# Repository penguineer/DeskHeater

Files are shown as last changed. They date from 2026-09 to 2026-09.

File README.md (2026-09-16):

# Desk Heater

> Low-power heated desktop for reducing conductive heat loss while working in a cool room.

This project adds a thin 24 V carbon heating film underneath a bamboo desktop. The goal is not to make the desk feel hot, but to keep the work surface close enough to room/body-neutral temperature that it no longer cools hands and forearms during long work sessions in winter.

The controller is based on an ESP8266 (ESP-12E) and provides:

- temperature monitoring with multiple NTC sensors
- hardware over-temperature protection independent of the ESP
- current, voltage, power and energy measurement
- slow duty-cycle control of the approximately 60 W heating film
- UART and Wi-Fi connectivity for monitoring and future controls

The KiCad design for the controller is in [`Controller/`](Controller/).

## Status

Work in progress. The electrical and mechanical design is currently being prototyped and characterized.

## License



This work is licensed under a [Creative Commons Attribution-ShareAlike 4.0 International License](http://creativecommons.org/licenses/by-sa/4.0/).

BY: Stefan Haun (mail@tuxathome.de)

See [LICENSE.txt](LICENSE.txt) for details.

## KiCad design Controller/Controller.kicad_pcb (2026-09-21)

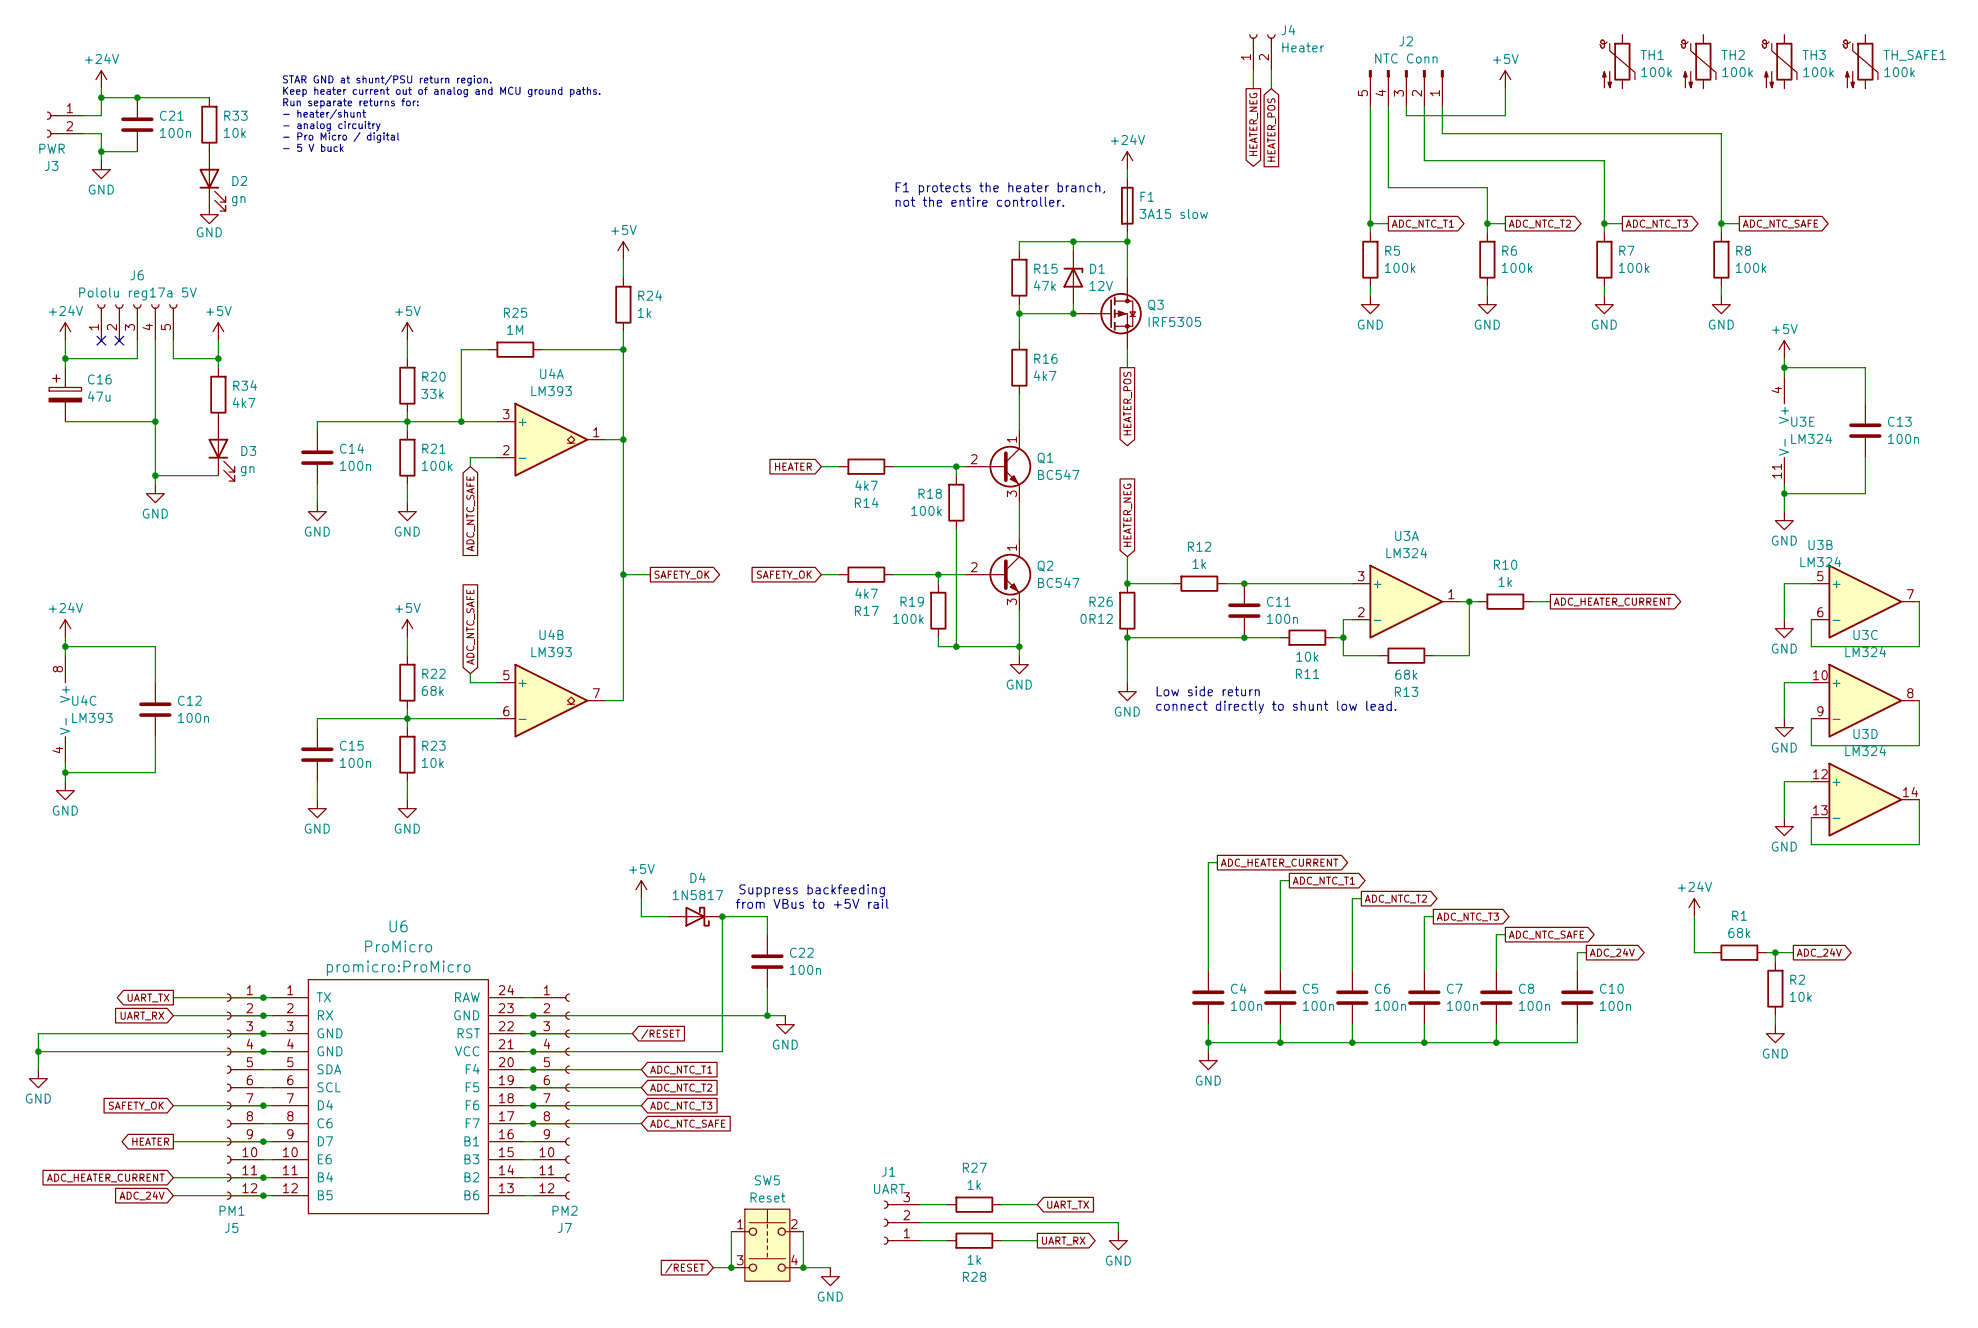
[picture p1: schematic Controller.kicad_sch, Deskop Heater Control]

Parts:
C4, C5, C6, C7, C8, C10, C11, C12, C13, C14, C15, C21, C22: 100n; C_Disc_D4.3mm_W1.9mm_P5.00mm
C16: 47u; CP_Radial_D6.3mm_P2.50mm
D1: 12V; D_DO-41_SOD81_P7.62mm_Horizontal
D2, D3: gn; LED_D3.0mm
D4: 1N5817; D_DO-41_SOD81_P10.16mm_Horizontal
F1: 3A15 slow; Fuseholder_Cylinder-5x20mm_Stelvio-Kontek_PTF78_Horizontal_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
J1: UART; PinHeader_1x03_P2.54mm_Vertical
J2: NTC Conn; JST_EH_B5B-EH-A_1x05_P2.50mm_Vertical
J3: PWR; JST_NV_B02P-NV_1x02_P5.00mm_Vertical
J4: Heater; JST_NV_B02P-NV_1x02_P5.00mm_Vertical
J5: PM1; PinSocket_1x12_P2.54mm_Vertical
J6: Pololu reg17a 5V; PinHeader_1x05_P2.54mm_Vertical
J7: PM2; PinSocket_1x12_P2.54mm_Vertical
Q1, Q2: BC547; TO-92_Inline
Q3: IRF5305; TO-220-3_Vertical
R1, R13, R22: 68k; R_Axial_DIN0207_L6.3mm_D2.5mm_P7.62mm_Horizontal
R2, R11, R23, R33: 10k; R_Axial_DIN0207_L6.3mm_D2.5mm_P7.62mm_Horizontal
R5, R6, R7, R8, R18, R19, R21: 100k; R_Axial_DIN0207_L6.3mm_D2.5mm_P7.62mm_Horizontal
R10, R12, R24, R27, R28: 1k; R_Axial_DIN0207_L6.3mm_D2.5mm_P7.62mm_Horizontal
R14, R16, R17, R34: 4k7; R_Axial_DIN0207_L6.3mm_D2.5mm_P7.62mm_Horizontal
R15: 47k; R_Axial_DIN0207_L6.3mm_D2.5mm_P7.62mm_Horizontal
R20: 33k; R_Axial_DIN0207_L6.3mm_D2.5mm_P7.62mm_Horizontal
R25: 1M; R_Axial_DIN0207_L6.3mm_D2.5mm_P7.62mm_Horizontal
R26: 0R12; R_Axial_DIN0614_L14.3mm_D5.7mm_P15.24mm_Horizontal
SW5: Reset; SW_DIP_SPSTx02_Slide_6.7x6.64mm_W7.62mm_P2.54mm_LowProfile
TH1, TH2, TH3: 100k; LQFP-100_14x14mm_P0.5mm
TH_SAFE1: 100k; LQFP-100_14x14mm_P0.5mm
U3: LM324; DIP-14_W7.62mm_LongPads
U4: LM393; DIP-8_W7.62mm_LongPads
U6: ProMicro

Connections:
+5V: C13.1, D4.2 (A), J2.3, J6.5, R20.2, R22.2, R24.2, R34.2, U3.4 (V+)
+24V: C12.1, C16.1, C21.1, F1.1, J3.1, J6.3, R1.1, R33.2, U4.8 (V+)
ADC_24V: C10.1, J5.12, R1.2, R2.2, U6.12 (B5)
ADC_HEATER_CURRENT: C4.1, J5.11, R10.1, U6.11 (B4)
ADC_NTC_SAFE: C8.1, J2.1, J7.8, R8.2, U4.2 (-), U4.5 (+), U6.17 (F7)
ADC_NTC_T1: C5.1, J2.5, J7.5, R5.2, U6.20 (F4)
ADC_NTC_T2: C6.1, J2.4, J7.6, R6.2, U6.19 (F5)
ADC_NTC_T3: C7.1, J2.2, J7.7, R7.2, U6.18 (F6)
GND: C4.2, C5.2, C6.2, C7.2, C8.2, C10.2, C11.2, C12.2, C13.2, C14.2, C15.2, C16.2, C21.2, C22.2, D2.1 (K), D3.1 (K), J1.2, J3.2, J5.3, J5.4, J6.4, J7.2, Q2.3 (E), R2.1, R5.1, R6.1, R7.1, R8.1, R11.2, R18.1, R19.1, R21.1, R23.1, R26.1, SW5.2, SW5.4, U3.5 (+), U3.10 (+), U3.11 (V-), U3.12 (+), U4.4 (V-), U6.3 (GND), U6.4 (GND), U6.23 (GND)
HEATER: J5.9, R14.2, U6.9 (D7)
HEATER_NEG: J4.1, R12.2, R26.2
HEATER_POS: J4.2, Q3.3 (S)
unnamed: D1.2 (A), Q3.1 (G), R15.1, R16.2
unnamed: D1.1 (K), F1.2, Q3.2 (D), R15.2
unnamed: D2.2 (A), R33.1
unnamed: D3.2 (A), R34.1
unnamed: C22.1, D4.1 (K), J7.4, U6.21 (VCC)
unnamed: J1.1, R28.2
unnamed: J1.3, R27.2
unnamed: J5.5, U6.5 (SDA)
unnamed: J5.6, U6.6 (SCL)
unnamed: J5.8, U6.8 (C6)
unnamed: J5.10, U6.10 (E6)
unnamed: J7.1, U6.24 (RAW)
unnamed: J7.9, U6.16 (B1)
unnamed: J7.10, U6.15 (B3)
unnamed: J7.11, U6.14 (B2)
unnamed: J7.12, U6.13 (B6)
unnamed: Q1.2 (B), R14.1, R18.2
unnamed: Q1.1 (C), R16.1
unnamed: Q1.3 (E), Q2.1 (C)
unnamed: Q2.2 (B), R17.1, R19.2
unnamed: R10.2, R13.1, U3.1
unnamed: C11.1, R12.1, U3.3 (+)
unnamed: R11.1, R13.2, U3.2 (-)
unnamed: U3.6 (-), U3.7
unnamed: U3.8, U3.9 (-)
unnamed: U3.13 (-), U3.14
unnamed: C14.1, R20.1, R21.2, R25.2, U4.3 (+)
unnamed: C15.1, R22.1, R23.2, U4.6 (-)
SAFETY_OK: J5.7, R17.2, R24.1, R25.1, U4.1, U4.7, U6.7 (D4)
UART_RX: J5.2, R28.1, U6.2 (RX)
UART_TX: J5.1, R27.1, U6.1 (TX)
/RESET: J7.3, SW5.1, SW5.3, U6.22 (RST)

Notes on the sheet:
Low side return connect directly to shunt low lead.
Suppress backfeeding from VBus to +5V rail
STAR GND at shunt/PSU return region. Keep heater current out of analog and MCU ground paths. Run separate returns for: - heater/shunt - analog circuitry - Pro Micro / digital - 5 V buck
F1 protects the heater branch, not the entire controller.

Board: 2 copper layers, 59 parts (0 on the bottom side), 35 nets, no tracks yet.

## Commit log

2026-09-16 Add controller schematic
    [Controller.kicad_pcb, Controller.kicad_sch]
2026-09-17 Refine voltage generation and add connectors
    [Controller.kicad_sch]
2026-09-17 Assign footprints
    [Controller.kicad_sch]
2026-09-17 Add connector for NTCs
    [Controller.kicad_sch]
2026-09-17 First attempt on board layout
    [Controller.kicad_pcb, Controller.kicad_sch]
2026-09-20 Switch to Teensy Pro Micro
    [Controller.kicad_pcb, Controller.kicad_sch]
2026-09-21 Suppress backfeeding from Vbus to +5V rail
    [Controller.kicad_pcb, Controller.kicad_sch]
